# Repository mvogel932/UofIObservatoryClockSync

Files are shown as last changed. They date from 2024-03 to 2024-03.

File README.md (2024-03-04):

# UofIObservatoryClockSync
Self-winding clock synchronizer with accurate timebase
Self-winding clock synchronizer:
Documentation/software:  https://github.com/mvogel932/UofIObservatoryClockSync

General info:

Master clock provides a one-second long pulse once per hour.  It connects the positive power lead to a terminal for that one second.  So what the clock sync circuit needs to do is close a relay for one second once an hour, exactly at 59 min 59 seconds past the hour, ending exactly at the hour.
Per email from Mike Svec on 5/7/23, the self-winding clock uses 3V power.   Bruce Hannon added a transformer on the inside to power the rewind.
Based on my research, it appears the sync coil on the self-winding clock should have a DC resistance of about 6 ohms.  So it will draw about 0.5 amps at 3 volts.

Rev 2 Hardware (as of 2/5/2024):

Controller board:  Adafruit ESP32-S2 Reverse TFT Feather
From <https://www.adafruit.com/product/5345> 

It's basically our ESP32-S2 TFT Feather but with the 240x135 color TFT display on the back-side not the front-side. That makes it great for panel-mounted projects, particularly since we've also got some space for 3 buttons to go along. It's like an all-in-one display interface dev board, powered by the fantastic ESP32-S2 WIFI module.
This feather comes with native USB and 4 MB flash + 2 MB of PSRAM, so it is perfect for use with CircuitPython or Arduino with low-cost WiFi. Native USB means it can act like a keyboard or a disk drive. WiFi means it's awesome for IoT projects. And Feather means it works with the large community of Feather Wings for expandability.
The ESP32-S2 is a highly-integrated, low-power, 2.4 GHz Wi-Fi System-on-Chip (SoC) solution that now has built-in native USB as well as some other interesting new technologies like Time of Flight distance measurements. With its state-of-the-art power and RF performance, this SoC is an ideal choice for a wide variety of application scenarios relating to the Internet of Things (IoT), wearable electronics, and smart homes.
Please note the Feather ESP32-S2 has a single-core 240 MHz chip, so it won't be as fast as ESP32's with dual-core. Also, there is no Bluetooth support. However, we are super excited about the ESP32-S2's native USB which unlocks a lot of capabilities for advanced interfacing! This ESP32-S2 mini-module we are using on the Feather comes with 4 MB flash and 2 MB PSRAM so you can buffer massive JSON files for parsing!
The color TFT is connected to the SPI pins, and uses additional pins for control that are not exposed to the breakout pads. It's the same display as you see here, with 240x135 pixels and is IPS so you get bright color at any angle. The backlight is also connected to a separate pin so you can PWM the backlight up and down as desired.
For low power usage, the Feather has a second RT9080 regulator. The regulator is controlled with a GPIO pin on the enable line and can shut off power to the Stemma QT port and TFT. There is also a separate power pin for the NeoPixel that can be used to disable it for even lower quiescent power. With everything off and in deep sleep mode, the TFT feather uses about 40uA of current.
Features:
	• ESP32-S2 240MHz Tensilica processor - the next generation of ESP32, now with native USB so it can act like a keyboard/mouse, MIDI device, disk drive, etc!
	• Mini module has FCC/CE certification and comes with 4 MByte of Flash and 2 MByte of PSRAM - you can have huge data buffers
	• Color 1.14" IPS TFT with 240x135 pixels - bright and colorful display with ST7789 chipset that can be viewed at any angle.
	• Three User Tactile buttons - D0, D1, and D2. D0/BOOT0 is also used for entering ROM bootloader mode if necessary.
	• Power options - USB type C or Lipoly battery
	• Built-in battery charging when powered over USB-C
	• LiPoly battery monitor - MAX17048 chip actively monitors your battery for voltage and state of charge / percentage reporting over I2C
	• Reset and DFU (BOOT0) buttons to get into the ROM bootloader (which is a USB serial port so you don't need a separate cable!)
	• Serial debug output pin (optional, for checking the hardware serial debug console)
	• STEMMA QT connector for I2C devices, with switchable power, so you can go into low power mode.
	• On/Charge/User LEDs + status NeoPixel with pin-controlled power for low power usage
	• Low Power friendly! In deep sleep mode, we can get down to 40~50uA of current draw from the Lipoly connection. Quiescent current is from the power regulator, ESP32-S2 chip, and Lipoly monitor. Turn off the NeoPixel and external I2C/TFT power for the lowest quiescent current draw.
	• Works with Arduino or CircuitPython

From <https://www.adafruit.com/product/5345> 

Relay board:  Adafruit power relay FeatherWing
https://www.adafruit.com/product/3191
Omron G5LE-14 3 VDC relay
Coil resistance:  22.5 Ohms
Coil current:  133 mA
Must operate voltage: 2.25 VDC
Must release voltage: 0.3 VDC
Operate time:  10 ms
Release time:  5 ms
Inductive load max:  4A at 30 VDC

GPS board: Adafruit Ultimate GPS FeatherWing
https://www.adafruit.com/product/3133

Connector for output to clock synchronizer solenoid:
5.5 x 2.1 mm DC Power Jack Socket Threaded Female Panel Mount Connector Adapter with Dustproof Plug 6Pack
Connector size: 5.5x2.1mm
Mounting hole diameter: 10.8mm

Power input(s) to sync circuit:  USB-C cable to 5.25V 1A plug in power transformer
Output signal to clock:   1 second pulse, 3V, 0.5 amps to power sync solenoid
Source of accurate time:  GPS
Software:  Arduino running on ESP32-S2
Arduino sketch:  Custom software written by Matt Vogel
Arduino GPS library:  Adafruit GPS Library

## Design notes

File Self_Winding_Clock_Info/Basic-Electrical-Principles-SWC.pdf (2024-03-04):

Ken’s Clock Clinic
Clock Restorations and Vintage Dry Cells

1

# Basic Electrical Principles

## for Self Winding Clocks

# Ken Reindel NAWCC Chapter 15

Ken’s Clock Clinic
Clock Restorations and Vintage Dry Cells

2

# Objective

# - To de-mystify electrical principles - Enrich Understanding

## – Technical – How self-winding technology came into being

# - Offer solid technical foundation for working on Self-winding Clocks - This is NOT a course on self winding clock repair (that one is next!)

Ken’s Clock Clinic
Clock Restorations and Vintage Dry Cells

3

# Approach

# - Start with Historical Perspective - Explain simple mathematical relationships - Apply them with a mini lab - Discussion, answer questions

Ken’s Clock Clinic
Clock Restorations and Vintage Dry Cells

4

# Agenda

## - Historical - Basic Electricity - Ohm’s Law - Power Law

– Double the voltage, quadruple the trouble

## - Components

– Resistors
– Batteries
– Coils and Electromagnets
– Contacts

## - Making Basic Electrical Measurements

– Digital Multimeter Basics

## - Mini-Lab

Ken’s Clock Clinic
Clock Restorations and Vintage Dry Cells

5

# The 1700s

Benjamin Franklin, American inventor and politician. In 1752 he established that lightning and Static electricity were fundamentally the same. He also established the conventions of negatively charged electrons and positively charged protons.

Alessandra Volta, Italian mathematician. In 1792 he proved that brine-(saltwater) saturated paper sandwiched in between disks of silver and zinc would produce an electrical potential (electrical pressure). This was the origin of the BATTERY! The unit of electrical potential or pressure was named in his honor.

Ken’s Clock Clinic
Clock Restorations and Vintage Dry Cells

6

# Early 1800s

Andre-Marie Ampere, French Mathematician. In 1826, he published the results of his studies that related electric current flow to magnetism (but gave credit for it to Michael Faraday). The unit of electrical current flow was named after him.

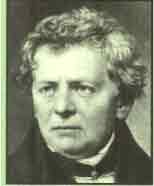
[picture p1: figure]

George Ohm, German Physicist and mathematician. In 1827 he published "The Galvanic Circuit Investigated Mathematically,” quantifying the relationships between electrical potential, electric current flow, and resistance. The unit of resistance was named after him.

Ken’s Clock Clinic
Clock Restorations and Vintage Dry Cells

7

# Significant Advances

Thomas Alva Edison, American Inventor: Between 1850 and well into the early 1900’s, Edison applied the theories of many predecessors to the invention or refinement of the incandescent light, DC motor, DC generator, and first practical storage battery.

Georges Leclanché, French Scientist and Engineer. In 1866 Leclanché developed the first practical 1.5 volt wet cell. Over 20,000 were produced to power telegraphs, clocks, doorbells. Was the forerunner of the Dry Battery (first realized by Carl Gassner and later E. M. Jewett) or modern carbon-zinc cell.

Ken’s Clock Clinic
Clock Restorations and Vintage Dry Cells

8

# The Atom

## - Composed of:

– Protons
– Neutrons
– Electrons

## - Protons and neutrons are tightly bound into a nucleus - Electrons are relatively loosely held and can be moved in and out of atomic shells

Electrons can be moved
from atom to atom by
electrical pressure

Electrons can also be
freed by chemical
reactions, creating
electrical pressure

Ken’s Clock Clinic
Clock Restorations and Vintage Dry Cells

9

# Insulators and Conductors

## Insulators are materials that do not readily allow the electrons in their atoms to move freely from atom to

atom. Examples are glass, wood, air.

## Conductors are materials that freely allow movement of electrons between the individual atoms. Metals are the primary

example.

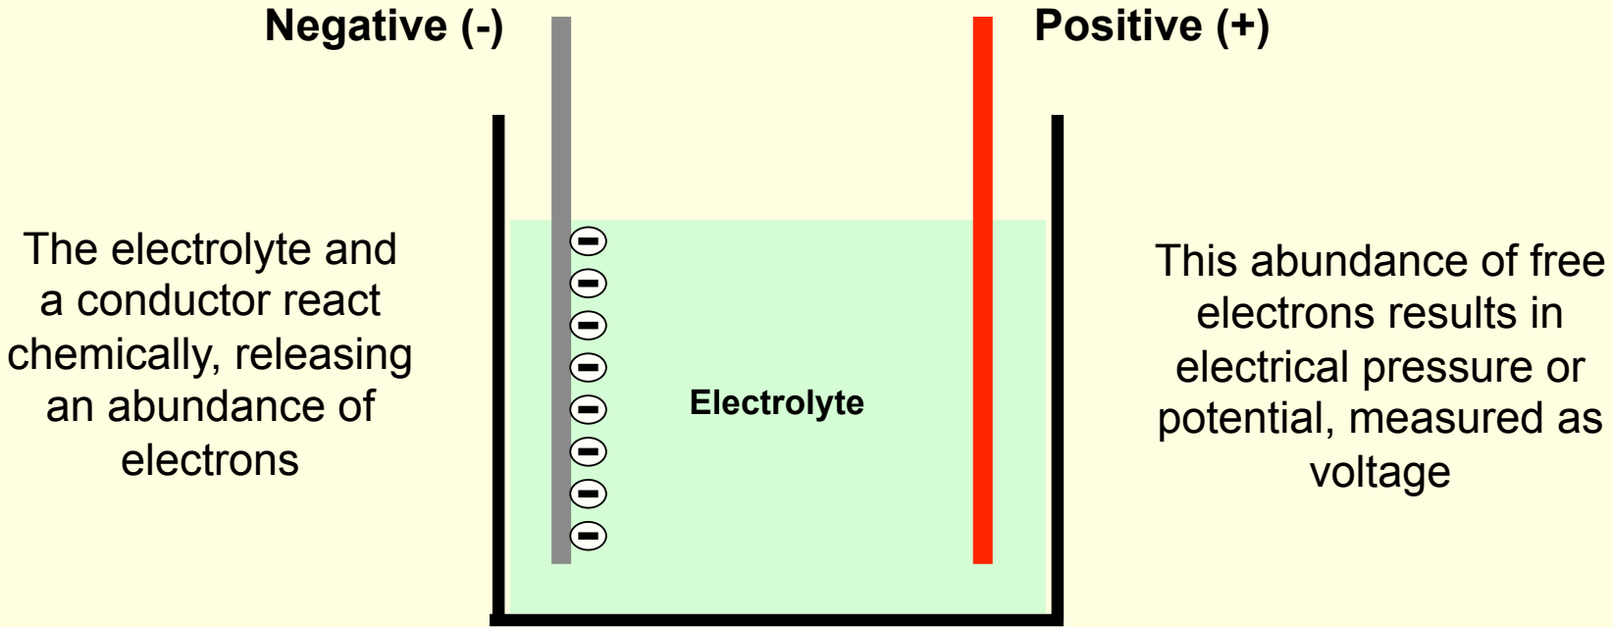
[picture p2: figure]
Negative (-); Positive (+); Electrolyte; The electrolyte and a conductor react chemically, releasing an abundance of electrons; This abundance of free electrons results in electrical pressure or potential, measured as voltage

Ken’s Clock Clinic
Clock Restorations and Vintage Dry Cells

10

# How Batteries Work

## - A device for storing electrical pressure or potential - Consists of 2 conducting plates and an electrolyte

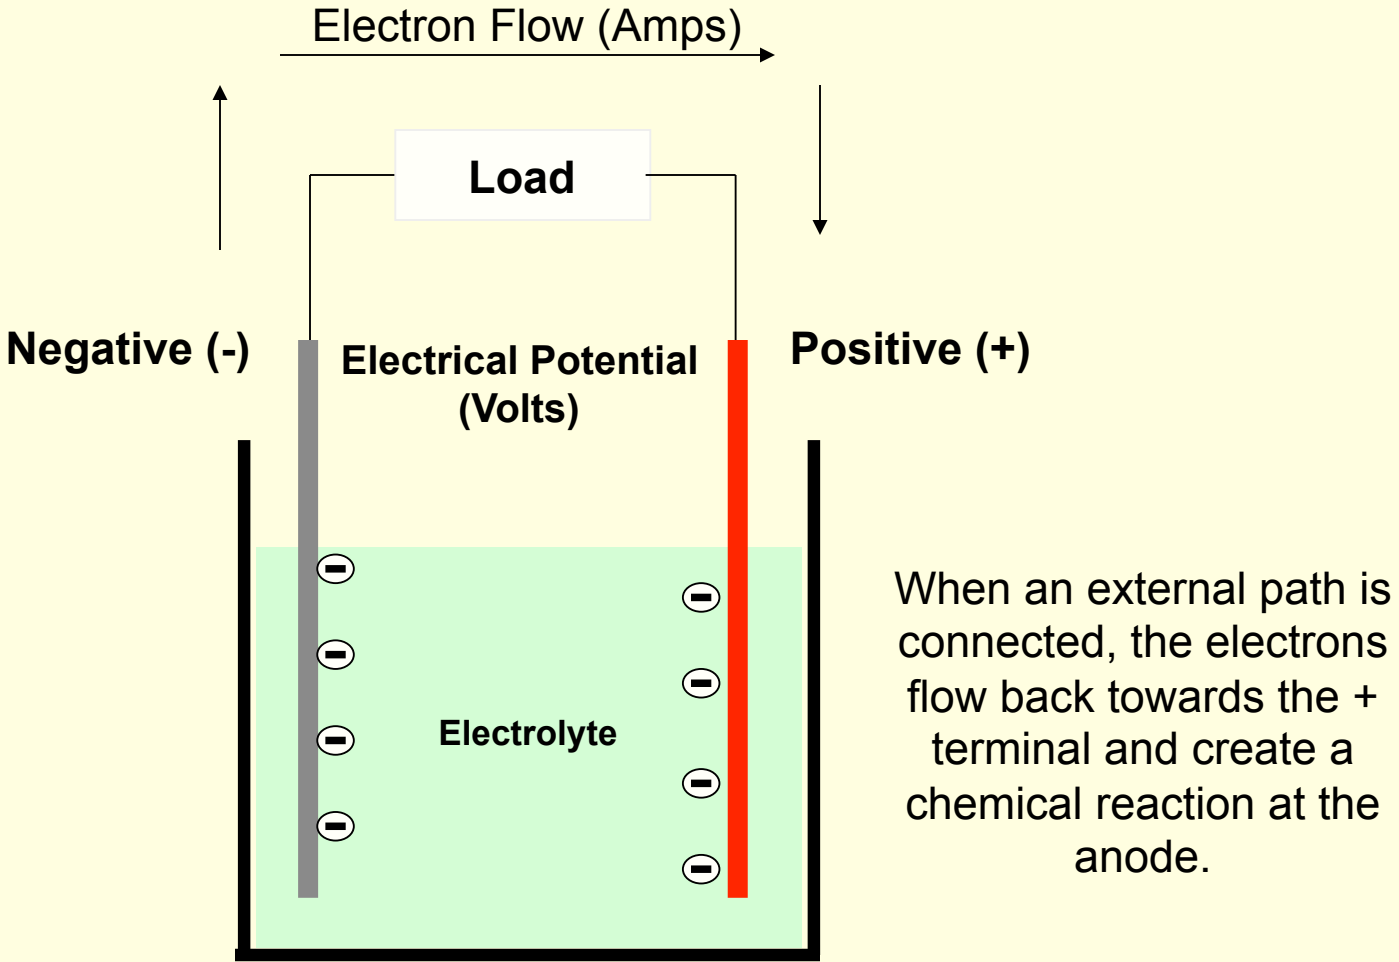
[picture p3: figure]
Load; Electrolyte; Negative (-); Positive (+); Electron Flow (Amps); When an external path is connected, the electrons flow back towards the + terminal and create a chemical reaction at the anode.; Electrical Potential (Volts)

Ken’s Clock Clinic
Clock Restorations and Vintage Dry Cells

11

# Battery Connected

Ken’s Clock Clinic
Clock Restorations and Vintage Dry Cells

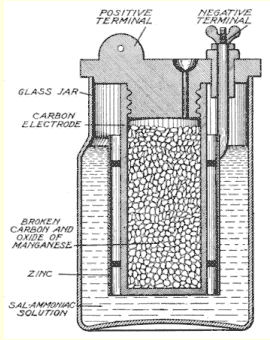
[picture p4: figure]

12

# The Leclanché Cell

# - Earliest practical battery (1866-1900) - Forerunner of Dry Battery - Patented; over 20,000 built - Had a tendency to spill - 1.5 volt cell

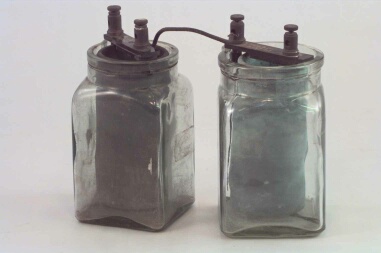
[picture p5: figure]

Ken’s Clock Clinic
Clock Restorations and Vintage Dry Cells

13

# Gonda™ Leclanché Cells

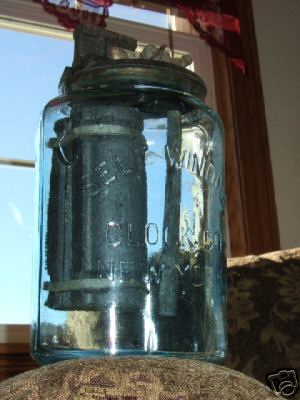
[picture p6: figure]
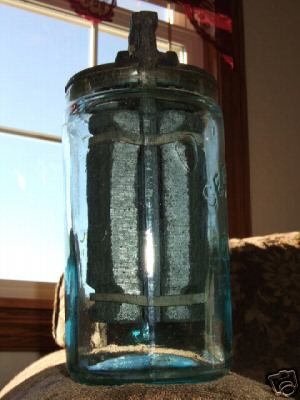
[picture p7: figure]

Ken’s Clock Clinic
Clock Restorations and Vintage Dry Cells

14

# Self Winding Clock Co. Wet Cell

$180 on Ebay

Ken’s Clock Clinic
Clock Restorations and Vintage Dry Cells

15

# The Columbia Battery

## - National Carbon Co. of Lakewood, OH

## – Founded in 1894 – Originally manufactured Leclanché cells – Decades later became Eveready and then Energizer

## - E. M. Jewett and George Little

## – Developed a zinc can-based cell in 1896 – Used carbon as the center cathode (+) – Acidic paste electrolyte with a cardboard separator

– Powered telephone, doorbells, automobiles (ignitor), self-winding clocks, lanterns, etc.

## – Transformed the industry!

# The Columbia Battery

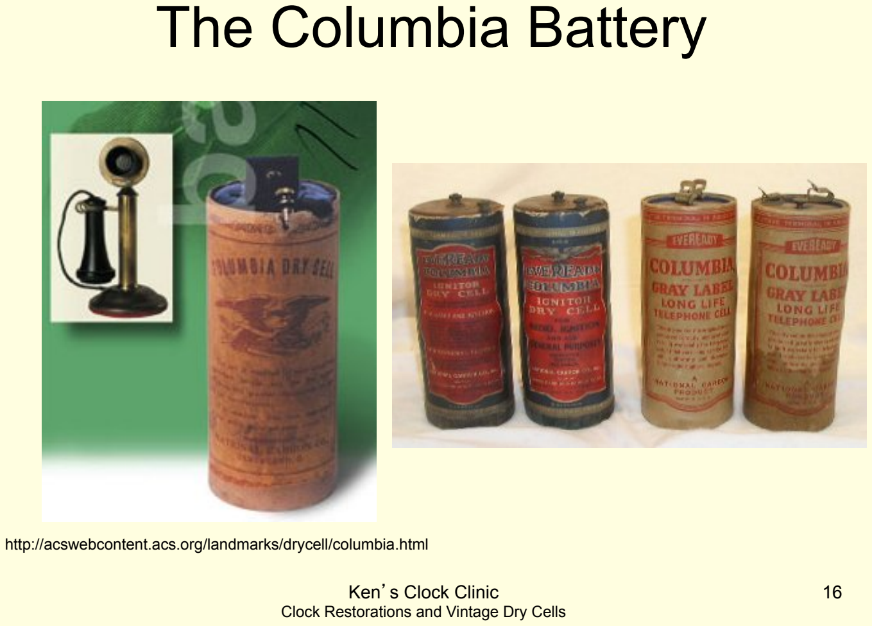
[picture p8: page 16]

Ken’s Clock Clinic
Clock Restorations and Vintage Dry Cells

16

http://acswebcontent.acs.org/landmarks/drycell/columbia.html

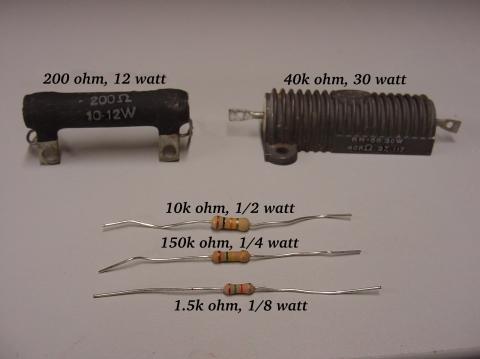
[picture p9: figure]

Ken’s Clock Clinic
Clock Restorations and Vintage Dry Cells

17

# Resistors

# - Many electrical loads are resistive (at least partially)

– Motors, light bulbs, electromagnets, etc.

# - Other examples of resistors:

Resistors are measured in Ohms (Ω)

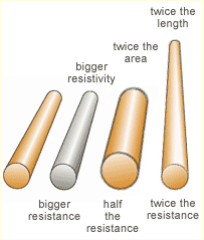
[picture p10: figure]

Ken’s Clock Clinic
Clock Restorations and Vintage Dry Cells

18

# Wire Resistance

# - Wire resistance varies by length and thickness - Also depends on the

type of wire e.g.,

# copper or NiCr

Ken’s Clock Clinic
Clock Restorations and Vintage Dry Cells

19

# SWCC Damping Resistors

Ken’s Clock Clinic
Clock Restorations and Vintage Dry Cells

20

# Elements of Electricity

# - Voltage

## – Electrical Pressure or Potential – Batteries are an example of a voltage source

# - Current

## – A measure of the FLOW of electricity – Measured in Amps

# - Resistance

## – A measure of the restriction to FLOW – Measured in Ohms

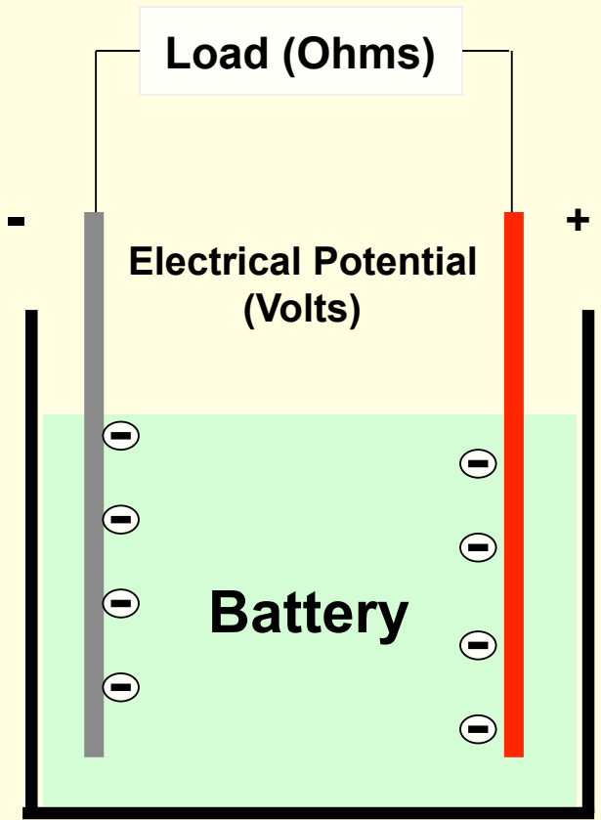
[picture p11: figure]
Load (Ohms); Battery; - + Electrical Potential (Volts)

Ken’s Clock Clinic
Clock Restorations and Vintage Dry Cells

21

# Elements of Electricity

Electron Flow
(Amps)

Power (Watts) = Amps x Volts

Voltage = Amps x Ohms

Also,

Amps = Voltage/Ohms

Ohm’s Law:

Power (Watts) = Volts²/Ohms

## Power is a measure of energy

Ken’s Clock Clinic
Clock Restorations and Vintage Dry Cells

22

# Example Application of Ohm’s Law

## Coil resistance = 6Ω Battery voltage = 3 volts

## How many amps will be needed from battery?

## Answer: Amps = Volts/Ohms = 3 volts/ 6Ω = ½ Amp

6Ω coil

+
3 V

Amps = ?

Ken’s Clock Clinic
Clock Restorations and Vintage Dry Cells

23

Let’s keep going…..

## - For the same circuit:

## How much power is dissipated in the coil?

## Answer:

## Power = Voltage²/Ohms = 3² volts/6Ω = 1.5 watts

6Ω coil

+
3 V

½ Amp

Power = ??

Ken’s Clock Clinic
Clock Restorations and Vintage Dry Cells

24

# One more time…

## - For the same circuit:

## How much more power is dissipated in the coil if we use a Lantern battery which is 6 volts???

## Answer:

# Power = Voltage²/Ohms

## = 6² volts/6Ω = 6 watts or 4x more!!

6Ω coil

+
6 V

Power = ??

1 Amp

Ken’s Clock Clinic

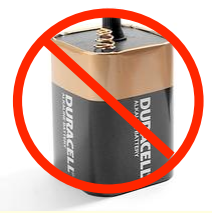
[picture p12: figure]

Clock Restorations and Vintage Dry Cells

25

Lesson Learned…..

# - Double the voltage (6V) forces 4x the energy into the electrical components

# - DO NOT USE in 3V clocks

## – Unless you use a voltage converter

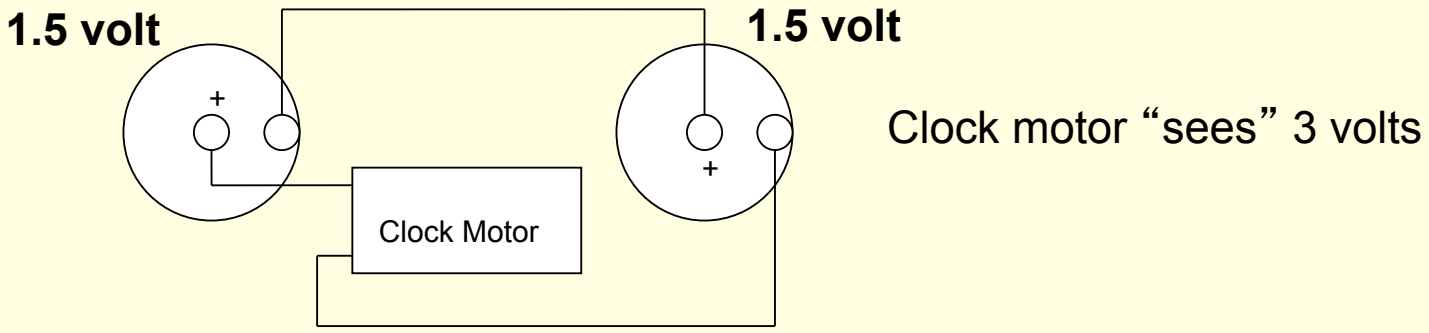
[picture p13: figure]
Clock Motor; 1.5 volt; Clock motor “; sees; ” 3 volts

Ken’s Clock Clinic
Clock Restorations and Vintage Dry Cells

26

# Series Circuits

# - Batteries in SERIES add:

# - Resistors in SERIES also add:

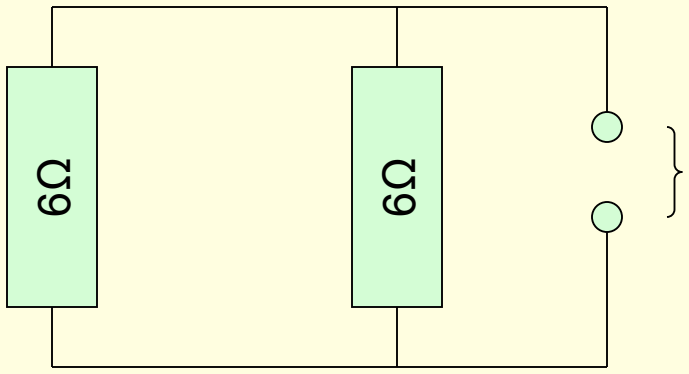
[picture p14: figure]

Ken’s Clock Clinic
Clock Restorations and Vintage Dry Cells

27

# Parallel Circuits

## - Batteries in PARALLEL of same voltage will output that voltage, but increase Amperage capacity

N like value resistors in
parallel reduce by:

Rp = R/N

6Ω// 6Ω = 3Ω

Ken’s Clock Clinic
Clock Restorations and Vintage Dry Cells

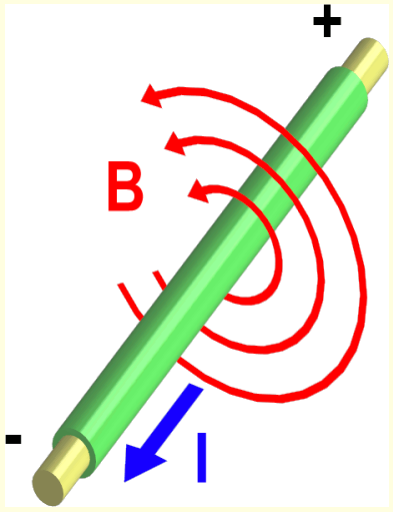
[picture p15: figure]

28

# Coils and Electromagnets

# - If a current is passed through a wire, a magnetic field results - This magnetic field encircles the wire as

shown.

# - The magnetic field will form around magnetic materials if we let it

Ken’s Clock Clinic

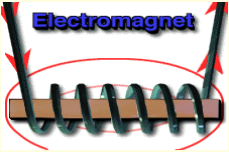
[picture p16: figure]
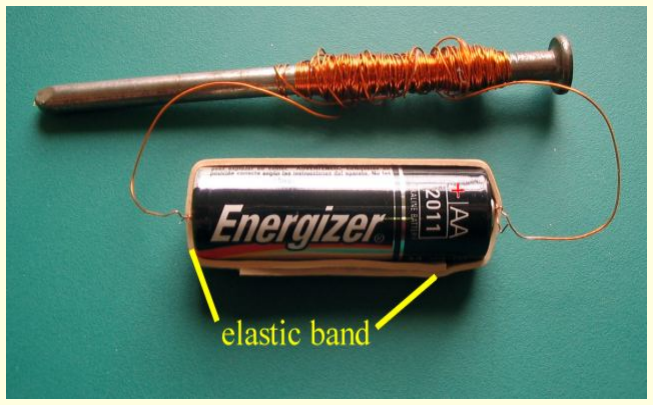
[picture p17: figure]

Clock Restorations and Vintage Dry Cells

29

# Coils and Electromagnets

## •Winding multiple turns around a core will concentrate the magnetic field as

shown.

## •An example of a simple electromagnet can be made using enameled wire wrapped around a nail!

## •All coils have some winding resistance resulting from the copper

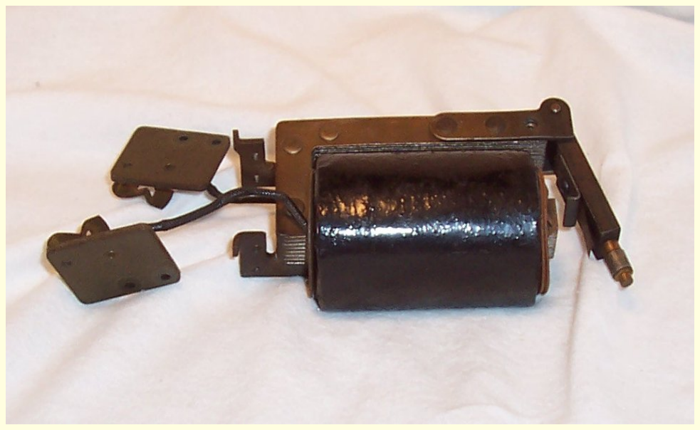
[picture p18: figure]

Ken’s Clock Clinic
Clock Restorations and Vintage Dry Cells

30

# Challenges with Coils

## - What happens when I energize this synchronizer coil?

## - Current will flow through the coil

## - Amps = V/(coil R)

## - Example: If V =3 volts and R is 6 Ω, then:

## Amps = 3V/6Ω = 0.5 Amp

Ken’s Clock Clinic

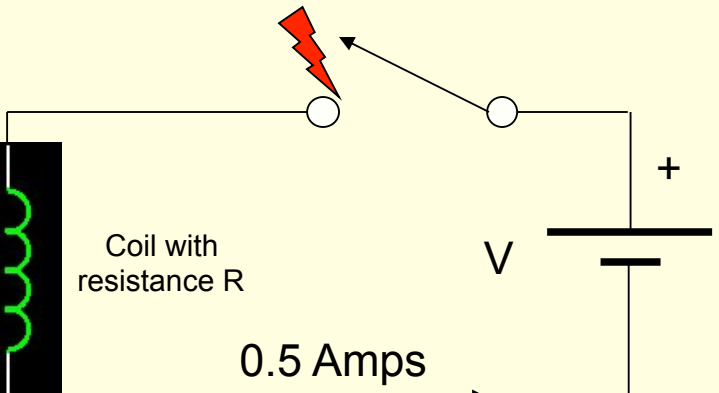
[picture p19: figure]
Coil with; resistance R; 0.5 Amps

Clock Restorations and Vintage Dry Cells

31

# Challenges with Coils

# - What happens when we disconnect the coil?

### 1. Energy is stored in the coil as an

electromagnetic field. That’s the nature of a coil.

### 2. So, when the switch is opened, the

current will want to keep flowing in the coil.

### 3. It will increase its voltage until the

contact arcs over (100’s or 1000’

s
of volts).

### 4. The “spot” temperature from this

arc is hot enough to melt metal, thus pitting and damaging the contacts.
-1000V
3V | 0V

Waveform at Contact

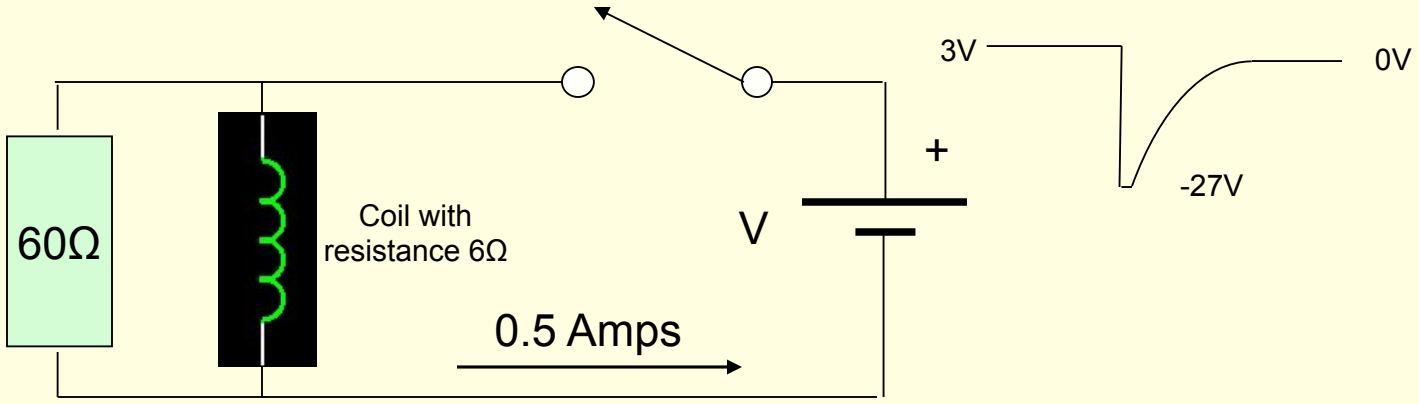
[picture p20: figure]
Coil with; resistance 6Ω; 0.5 Amps

Ken’s Clock Clinic
Clock Restorations and Vintage Dry Cells

32

# Challenges with Coils

# - Question: How do I prevent this? - Answer: Create somewhere else for the

coil current to go when the contact opens.

Flyback current

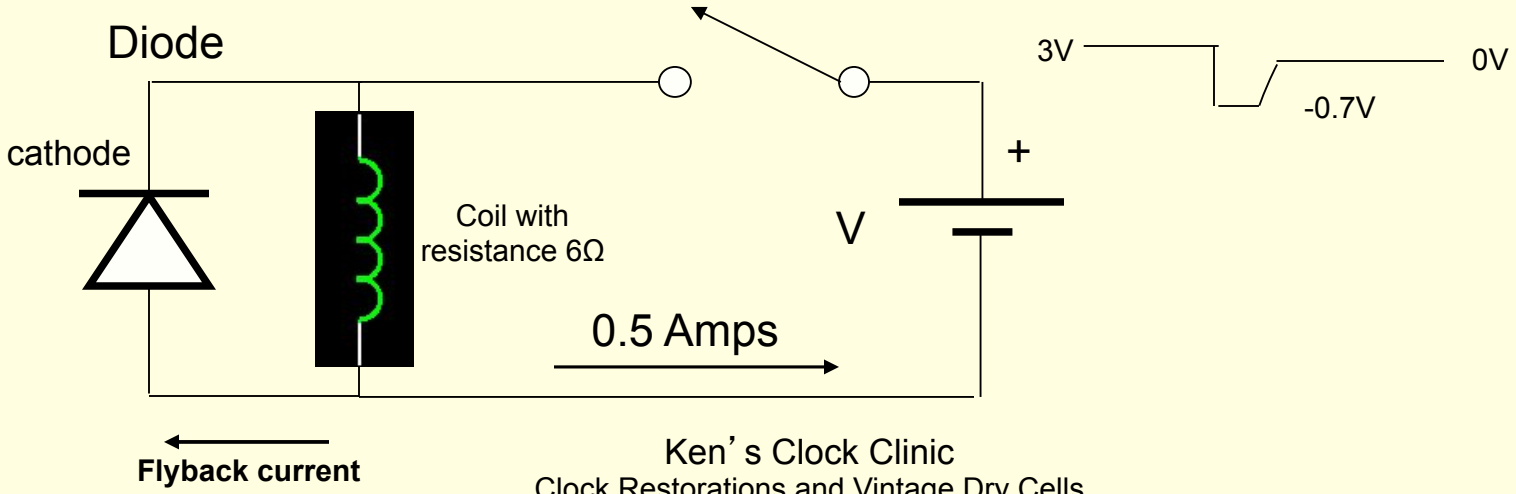
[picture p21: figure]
Ken’s Clock Clinic; Coil with; resistance 6Ω; 0.5 Amps; Flyback current; cathode; Diode

Clock Restorations and Vintage Dry Cells

33

# Challenges with Coils

- Most common option is a Damping resistor,

## usually selected to be 10x the value of the coil

resistance.

## - Another option is a diode, but this was obviously

not used in vintage days.

Ken’s Clock Clinic
Clock Restorations and Vintage Dry Cells

34

# Contacts

# - What makes a good contact???

– Largely depends on the application, but….

# - Low contact resistance - Resistant to oxidation

## – And, therefore, burning – Probably also means high melting temp

# - Good hardness—wears well over time

Ken’s Clock Clinic
Clock Restorations and Vintage Dry Cells

35

# Contacts

## - What kind of materials offer these qualities?

Material | Low Contact R | Resistance to Surface Films | Hardness (wears well)
Gold | Better | Best | Poor
Platinum | Better | Best | Better (especially Platinum-Iridium)
Silver | Best (initially) | Fair | Good
Tungsten | Good | Good | Best
Copper | Best (initially) | Poor | Poor

Ken’s Clock Clinic
Clock Restorations and Vintage Dry Cells

36

# Contacts

# - Platinum is the best pure material (non alloy) - Platinum-iridium is great because of additional hardness - Unfortunately both are VERY EXPENSIVE - But they are WORTH IT!

## – Clocks restored with platinum will run much longer

Ken’s Clock Clinic
Clock Restorations and Vintage Dry Cells

37

# DeoxIT® and DeoxIT® Gold G100L

## - Caig Laboratories - Proven over 50 year history - Unbelievable results – Examples

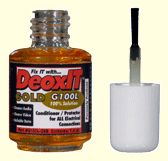
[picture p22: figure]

## - Only a very small quantity needed on CLEAN contacts to preserve them indefinitely

## – Don’t flood contact with it

## - Possible lubricant for Style A motor bearings and commutators

# - http://store.caig.com

ACCT113 2292 1560 AR5GrWbv 1627 http://store

Ken’s Clock Clinic

Clock Restorations and Vintage Dry Cells

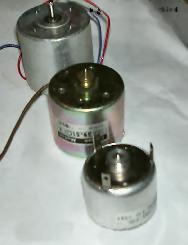
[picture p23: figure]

38

# Electric Motors

## - Electromagnetism is exploited

– Opposite magnetic poles attract; like poles repel

## - Rotation causes reversal of the electromagnetic field because of the commutator

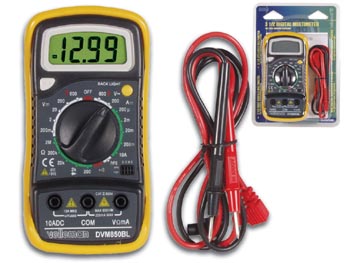
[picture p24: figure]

Ken’s Clock Clinic
Clock Restorations and Vintage Dry Cells

39

# Basic Electrical Measurements

## - The standard instrument for basic electrical measurements is the DMM (Digital MultiMeter) - Multi Function

– Volts
– Ohms
– Amps
– Continuity
– Diode Test

## - Accuracy ~1%

– Good enough for most if
not all clock work

Ken’s Clock Clinic
Clock Restorations and Vintage Dry Cells

40

# Important Aspects of DMM Measurements

## - Know your DMM

## – Make sure the range is appropriate for what you expect to measure!! – Make sure the leads are in the right place – Make practice measurements before doing anything real

## - Make sure you have a good zero

## – If you don’t, subtract the offset from your measurement to obtain most accurate reading – Especially true with low voltages

Ken’s Clock Clinic
Clock Restorations and Vintage Dry Cells

41

# Experiment 1: Measure the resistance of devices

# - Set DMM to 200 ohm range

# 1. Touch both probe tips to a terminal 2. Record “offset” 3. Measure device of interest eg Terminal 3 and Terminal 4 4. Subtract value in Step 2 from value in

Step 3.

Ken’s Clock Clinic
Clock Restorations and Vintage Dry Cells

42

# Experiment 2: Measuring Voltage

# - Set DMM to 20 Volts DC range

1. Measure battery terminal voltage.

# 2. Now, connect battery to light bulb

(Terminals 5 and 6).
3. Measure battery terminal voltage again.
4. Compare result from 2 to result from 4.

Ken’s Clock Clinic
Clock Restorations and Vintage Dry Cells

43

# Experiment 3: Stall Current of Motor

# - Connect a wire between Terminal 2 and Terminal 6 - Connect battery (with test clips) between Terminal 1 and Terminal 5 - Stop motor with fingers - What happens??? Why???

Ken’s Clock Clinic
Clock Restorations and Vintage Dry Cells

44

# Experiment 4: Coil Arcing

## 1. Connect one of the battery leads to Terminal 3

using test clip.

## 2. Touch other test clip to Terminal 4 3. As you do, notice the spark. Why is there a spark there? 4. Now, connect Terminal 3 to Terminal 7

5. Likewise connect Terminal 4 to Terminal 8.
6. Repeat the test in 1-2 above.

## - What happened? Why?

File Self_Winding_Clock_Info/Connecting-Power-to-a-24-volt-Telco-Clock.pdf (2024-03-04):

### Connecting Power to a 24 volt Telco Clock

Below is a picture of a typical Self Winding Clock Co. 24 volt Telco parlor clock, taken with the dial removed. This particular clock does not have a synchronizer coil. Note that the upper movement terminal on the left, marked A, connects to the Fahenstock terminal C which connects to the manual winding switch. This is very important in order for the winding switch to work properly and MUST NOT be connected anywhere else. Movement terminal B connects to Fahenstock terminal D. Be sure that the black curled grounding wire, which connects to the winding switch, is in place. This is a good time to make sure that the contact areas of the winding switch are clean. If not, remove the switch and clean it with Scotch-Brite. Do not use Scotch-Brite near the movement since it will generate abrasive dust and you don’t want that getting into the movement.

The 24 volt DC battery or power source is then connected to terminals E and F. Polarity is not important. Again, be sure that these and all other terminals are clean and oxidefree. If they remain oxidized and dirty, you may experience intermittent connections. The remaining terminals and switches in the clock are not used. They were originally meant to provide the 6 second timing signals to the billing system or printer. Don’t connect batteries to these terminals or switches.


The next picture shows the wiring installed as described above, but in addition, also shows the Model 1900R-24V connected to the clock. Note that the black and red battery wires are connected to terminals E and F as described above.

The following are some close ups showing the battery and the terminal connections above:

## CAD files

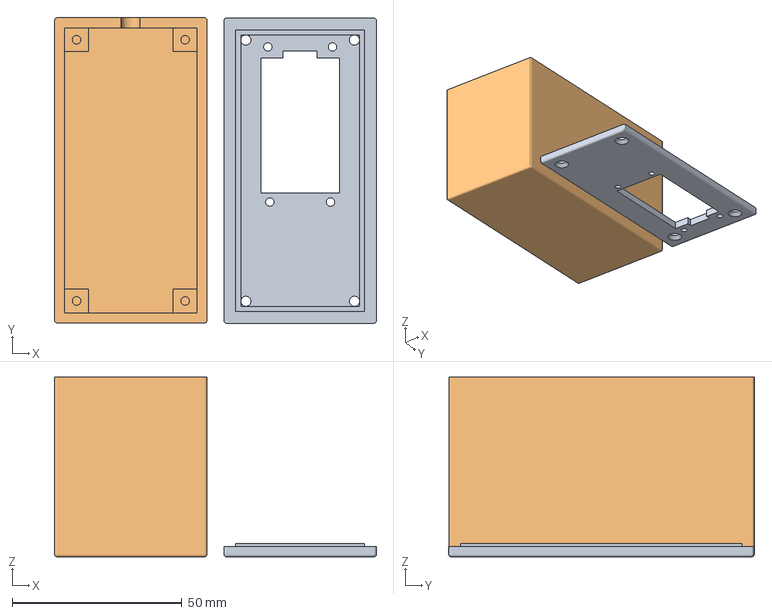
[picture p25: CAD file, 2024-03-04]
Case/Case v7.3mf
94.9 x 90.1 x 53.0 mm
CaseCover v10.stl
Case v7.stl

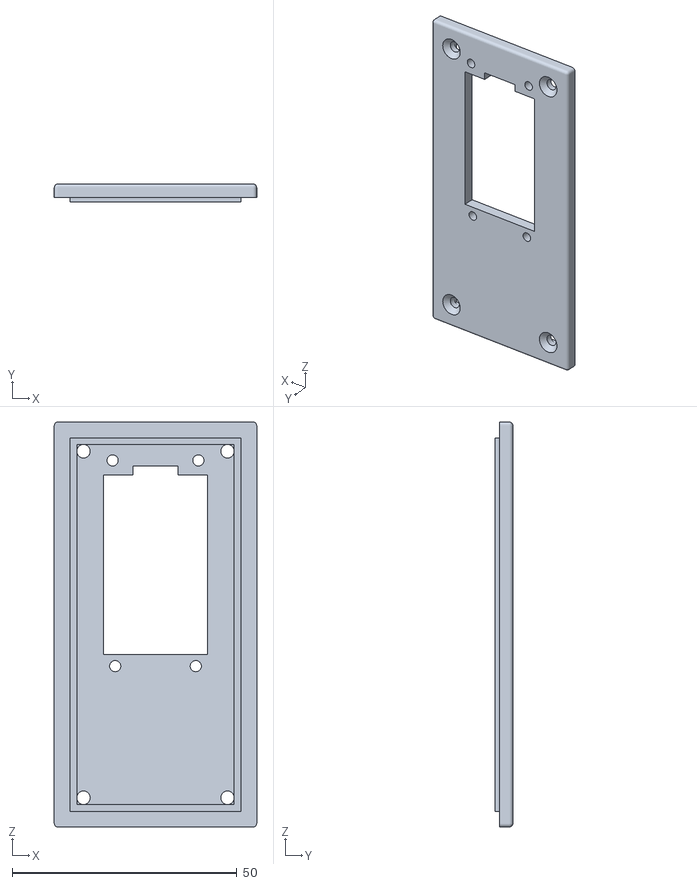
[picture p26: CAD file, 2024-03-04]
Case/CaseCover v10.stl
45.0 x 4.00 x 90.0

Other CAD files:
Case/Case v7.stl

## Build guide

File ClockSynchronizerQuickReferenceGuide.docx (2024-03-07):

University of Illinois Observatory self-winding clock synchronizer

Quick Reference Guide

Version: 1.0 Date: 3/7/2024 Author: Matthew Vogel

Summary:

The self-winding clock synchronizer is intended to be used with the self-winding clock in the Observatory. The synchronizer outputs a one second long pulse to the synchronizing coil of the self-winding clock once an hour, starting at 59 minutes, 59 seconds past the hour. This synchronizes the clock and ensures that the clock maintains the correct time. The synchronizer gets its time base from the GPS satellites.

Connecting the synchronizer:

The synchronizer has a connector for sending the sync pulse signal to the clock. The connector is a two conductor 5.5 x 2.1mm jack mounted on the side of the synchronizer. Wire a two-conductor cable to a matching 5.5 x 2.1mm plug, then connect the other end of the two wires to the two terminals of the synchronizer coil inside the clock. The synchronizer output pulse is powered by the internal lithium-ion battery of the synchronizer, so the output voltage will be between 3.7V and 4.2V, depending on the state of charge of the battery.

Powering the synchronizer:

The synchronizer has an internal battery that will run the synchronizer for about 10 hours. To keep this battery charged, plug the USB cable from the synchronizer into a suitable USB power supply (anything that can output 5V and at least 0.5A). To power off the synchronizer, unplug the USB cable from the power supply and turn off the power switch on the side of the synchronizer. During normal use, ensure that the power switch is “on” in order to keep the battery charged.

Using the synchronizer:

Once the synchronizer is powered and connected to the clock, it should automatically start sending the sync pulse to the clock once an hour, as long as the synchronizer can get a signal from the GPS satellites to maintain its internal time base.

There are three buttons to the left of the display on the synchronizer:

Button 1 (top): This button can be used to enable/disable the synchronizer output pulse. Each press of the button toggles the enable/disable state of the sync output. Note that the sync output cannot be enabled if the synchronizer is unable to get a GPS signal to maintain its internal time base.

Button 2 (middle): This button can be used to manually trigger the synchronizer output pulse (e.g., for testing the clock’s synchronizer coil). The sync output will be active for as long as this button is pressed.

Button 3 (bottom): This button is not used.

Location of documentation:

https://github.com/mvogel932/UofIObservatoryClockSync

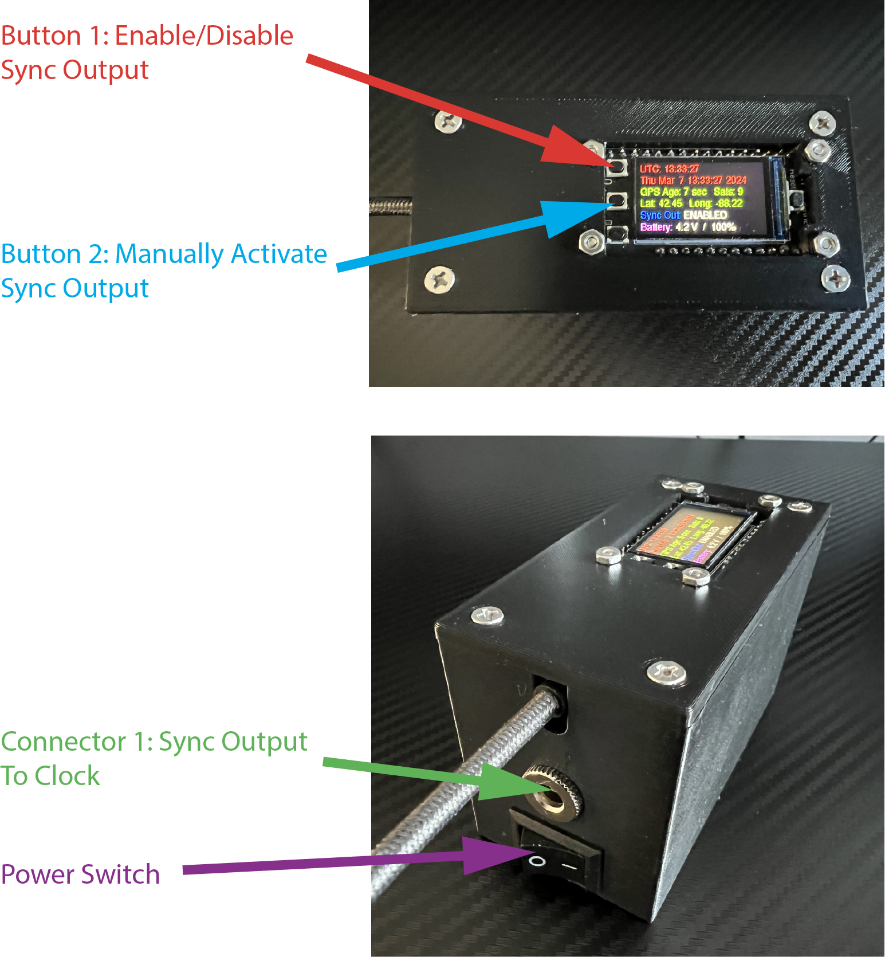
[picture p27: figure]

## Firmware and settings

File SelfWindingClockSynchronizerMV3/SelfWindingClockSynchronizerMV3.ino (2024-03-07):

/*
* Self-winding clock synchronizer software
*
* The purpose of this software is to maintain an accurate timebase and send a synchronizing pulse once an hour to a
* self-winding clock.
*
* The accurate timebase is obtained from GPS satellites.
*
* Hardware is based on the following:
*
* - Adafruit ESP32-S2 Reverse TFT Feather ( https://www.adafruit.com/product/5345 )
*   - Contains:
*     - ESP32-S2 Tensilica SOC, 240 MHz single-core, native USB, WiFi
*     - 1.14" 240x135 pixel color TFT display with ST7789 chipset
*     - 4 MB flash memory
*     - 2 MB PSRAM memory
*     - MAX17048 lithium-ion battery charge/fuel gauge IC
*     - STEMMA QT connector (JST SH 4-pin) for I2C devices
*     - NeoPixel RGB LED status indicator
*     - Three user interface buttons
*     - USB-C connector for charging lithium-ion battery and for serial communications with a PC
*
* - Adafruit Ultimate GPS FeatherWing ( https://www.adafruit.com/product/3133 )
*
* - Adafruit Power Relay FeatherWing ( https://www.adafruit.com/product/3191 )
*
*
* Arduino libraries:
* - Adafruit_MAX1704X - Library for MAX17048 lithium-ion fuel gauge IC
* - Adafruit_NeoPixel - Library for Adafruit NeoPixel single-wire based RGB LED pixel
* - Adafruit_ST7789   - Library for Adafruit 1.14" color TFT display with SPI and ST7789 TFT driver
* - Adafruit_GPS      - Library for Adafruit GPS module
* - ESP32Time         - Library for setting and retrieving internal RTC time on ESP32 boards, by fbiego
*
* Inputs:
*   D0 : ENABLE_DISABLE_OUTPUT - Enable/disable sync relay output (pin pulled HIGH by default, goes LOW when pressed)
*   D1 : TRIGGER_OUTPUT        - Manually trigger sync relay output (for as long as the button is held down) (pin pulled LOW by default, goes HIGH when pressed)
*
* Outputs:
*   Pin 10: Output signal to coil of relay for energizing the synchronizer of the self-winding clock (also red LED on relay board)
*   Pin 13: Output to red LED on ESP32 board (next to USB-C connector) (HIGH is on)
*
*/


// #defines
// Need to include this #define to have GPS library use hardware serial instead of software serial
#define NO_SW_SERIAL
#define GPSSerial Serial1
#define ONE_DAY_IN_SECONDS (60 * 60 * 24)
#define ONE_DAY_IN_MILLISECONDS (1000 * 60 * 60 * 24)
#define NUM_GPS_MSGS_RCVD_FOR_TIME_TO_BE_VALID    3
// Constants for GPIO outputs
#define ENABLE_DISABLE_OUTPUT             0
#define TRIGGER_OUTPUT                    1
#define CLOCK_SYNC                        10    /* Output pin for clock synchronizer relay control */
#define RED_LED                           13
#define ENABLE_DISABLE_OUTPUT_ACTIVE      LOW
#define TRIGGER_OUTPUT_ACTIVE             HIGH
#define RED_LED_ACTIVE                    HIGH
#define RED_LED_INACTIVE                  LOW

// #includes
#include <Arduino.h>
#include <Adafruit_GPS.h>
#include "Adafruit_MAX1704X.h"
#include <Adafruit_NeoPixel.h>
#include <Adafruit_ST7789.h>
#include "Adafruit_TestBed.h"
#include <ESP32Time.h>
#include <Fonts/FreeSans12pt7b.h>
#include <Fonts/FreeSans9pt7b.h>


// Global variables
uint8_t gMainLoopCounter = 0;                         // Main loop counter
bool gSynchronizerOutputManuallyDisabled = false;     // True if the synchronizer output is manually disabled
bool gRTCTimeValid = false;                           // True if the RTC time is valid
bool gGPSTimeValid = false;                           // True if the GPS time is valid
bool gRTCNeverSyncedToGPS = true;                     // Set to false the first time the RTC gets synced to GPS time base
nmea_float_t gSecondsSinceLastValidGPSTime;           // Seconds since the last valid GPS time was received (equal to 0 if never received)
unsigned long gTimeRTCLastSyncedToGPS = 0;            // Time (in milliseconds since board booted up) when RTC was last synced to GPS time base
uint32_t gNumGPSMsgsRcvd = 0;                         // Number of times a message has been received from the GPS module
bool gMAX17048_OK = true;                             // True if MAX17048 battery charger/fuel gauge IC is okay
bool gTriggerOutputActivePreviously = false;          // True if trigger output button was active previous time thru the loop
int  gPreviousPinValEnableDisableOutput;              // Previous pin value of enable/disable output button
int  gPreviousPinValTriggerOutput;                    // Previous pin value of trigger output button
extern Adafruit_TestBed TB;
Adafruit_MAX17048 gLiPo;                              // Adafruit lithium-ion battery charger/fuel gauge object
Adafruit_ST7789 gDisplay = Adafruit_ST7789(TFT_CS, TFT_DC, TFT_RST);  // Adafruit TFT LCD display object
GFXcanvas16 gCanvas(240, 135);                        // A GFX 16-bit canvas context for graphics, part of the Adafruit GFX graphics class
Adafruit_GPS GPS(&GPSSerial);                         // Adafruit GPS object for communicating with GPS module
ESP32Time rtc;                                        // ESP32 RTC object


//Function prototypes
void readGPS();                                       // Get data from GPS module
void syncRTCtoGPS();                                  // Sync the RTC to the GPS time base to keep the RTC accurate
void updateDisplay();                                 // Update the LCD display
void updateRTCTimeWithGPSTime();                      // Update the internal RTC time with the latest GPS time


// Setup
void setup() {
  // Set clock synchronizer GPIO pin to be an output and turn it off
  pinMode(CLOCK_SYNC, OUTPUT);
  digitalWrite(CLOCK_SYNC, LOW);

  Serial.begin(115200);
  //while (! Serial) delay(10);

  // Delay to allow serial to become ready
  delay(500);

  // Initialize the RTC
  rtc.setTime(0, 0, 14, 26, 2, 2024);                     // Default date/time to 2/26/2024 2:00 PM

  // Start the GPS software at 9600 baud rate
  GPS.begin(9600);
  GPS.sendCommand(PMTK_SET_NMEA_OUTPUT_RMCGGA);           // Turn on RMC (recommended minimum) and GGA (fix data)
  GPS.sendCommand(PMTK_SET_NMEA_UPDATE_100_MILLIHERTZ);   // 10 second update time
  GPS.sendCommand(PGCMD_ANTENNA);                         // Request updates on antenna status
  delay(1000);
  GPSSerial.println(PMTK_Q_RELEASE);                      // Ask for GPS firmware version

  // Start the NeoPixel RGB LED
  TB.neopixelPin = PIN_NEOPIXEL;
  TB.neopixelNum = 1; 
  TB.begin();
  TB.setColor(WHITE);

  // Start the LCD display
  gDisplay.init(135, 240);            // Init ST7789 240x135
  gDisplay.setRotation(3);
//  gCanvas.setFont(&FreeSans12pt7b);
  gCanvas.setFont(&FreeSans9pt7b);
  gCanvas.setTextColor(ST77XX_WHITE); 
  delay(500);

  // Activate the LCD backlight
  pinMode(TFT_BACKLITE, OUTPUT);
  digitalWrite(TFT_BACKLITE, HIGH);

  // Start the lithium ion battery charger/monitor
  if (!gLiPo.begin()) {
    Serial.println(F("Could not find Adafruit MAX17048?\nMake sure a battery is plugged in!"));
    gMAX17048_OK = false;
  }
  if (gMAX17048_OK) {
    Serial.print(F("Found MAX17048"));
    Serial.print(F(" with Chip ID: 0x")); 
    Serial.println(gLiPo.getChipID(), HEX);
  }

  // Set user buttons to be inputs
  pinMode(ENABLE_DISABLE_OUTPUT, INPUT_PULLUP);
  pinMode(TRIGGER_OUTPUT, INPUT_PULLDOWN);
  pinMode(2, INPUT_PULLDOWN);

  // Set red LED to be output
  pinMode(RED_LED, OUTPUT);
  digitalWrite(RED_LED, RED_LED_INACTIVE);

  // Set the previous state of the buttons to the current value so we don't detect a button press/release at startup
  gPreviousPinValEnableDisableOutput = digitalRead(ENABLE_DISABLE_OUTPUT);
  gPreviousPinValTriggerOutput       = digitalRead(TRIGGER_OUTPUT);

  Serial.println();
  Serial.println();
  Serial.println();
  Serial.println();
  Serial.println();
  Serial.println("************************************************");
  Serial.println("************************************************");
  Serial.println("********** Clock synchronizer startup **********");
  Serial.println("************************************************");
  Serial.println("************************************************");
}


// Main loop
void loop() {

  // Get data from the GPS module
  readGPS();

  // Update GPS time valid/not valid state
  // GPS time valid logic:
  // 1) When program first starts running, GPS time is invalid
  // 2) GPS time becomes valid when "time since last valid GPS time" becomes less than or equal to 120 seconds AND at least NUM_GPS_MSGS_RCVD_FOR_TIME_TO_BE_VALID GPS messages have been received
  // 3) GPS time becomes invalid when "time since last valid GPS time" becomes greater than 120 seconds

  // See how long it has been since we last received a valid GPS time
  gSecondsSinceLastValidGPSTime = GPS.secondsSinceTime();

  if ((gGPSTimeValid) && (gSecondsSinceLastValidGPSTime > 120)) {
    // Time is now invalid
    gGPSTimeValid = false;
    Serial.println("ERR: GPS TIME NOT VALID");
    Serial.print("Sec since valid: ");
    Serial.println(gSecondsSinceLastValidGPSTime);
  }

  if ( (!gGPSTimeValid) && (gSecondsSinceLastValidGPSTime <= 120) && (gNumGPSMsgsRcvd >= NUM_GPS_MSGS_RCVD_FOR_TIME_TO_BE_VALID) ) {
    // Time is now valid
    gGPSTimeValid = true;
    Serial.println("INFO: GPS TIME VALID");
    Serial.print("Sec since valid: ");
    Serial.println(gSecondsSinceLastValidGPSTime);
  }

  // Update RTC time valid/not valid state
  // RTC time valid logic:
  // 1) When program first starts running, RTC time is invalid
  // 2) RTC time becomes valid when RTC time gets synced to GPS time (handled lower down in the main loop)
  // 3) RTC time becomes invalid when "time since RTC time last synced to GPS time" becomes greater than 3 days

  if ( (gRTCTimeValid) && ( (millis() - gTimeRTCLastSyncedToGPS) > (3 * ONE_DAY_IN_MILLISECONDS) ) ) {
    // Time is now invalid
    gRTCTimeValid = false;
    Serial.println("ERR: RTC TIME NOT VALID");
    Serial.print("Sec since RTC synced to GPS: ");
    Serial.println(gTimeRTCLastSyncedToGPS / 1000);
  }


  // Check if we need to sync the RTC time to the GPS time base
  // RTC time gets synced to GPS time IF:
  //  GPS time is valid
  //      *AND*
  //  ( RTC has never been synced to GPS  *AND*  at least NUM_GPS_MSGS_RCVD_FOR_TIME_TO_BE_VALID GPS messages have been received
  //      *OR*
  //    More than one day has elapsed since RTC was last synced to GPS )
  //
  if ( gGPSTimeValid && ( ( (gRTCNeverSyncedToGPS) && (gNumGPSMsgsRcvd >= NUM_GPS_MSGS_RCVD_FOR_TIME_TO_BE_VALID) ) || ( (millis() - gTimeRTCLastSyncedToGPS > ONE_DAY_IN_MILLISECONDS) ) ) ) {
    gRTCNeverSyncedToGPS = false;
    gTimeRTCLastSyncedToGPS = millis();
    syncRTCtoGPS();
    // If RTC had been previously invalid, then do some stuff now that RTC is valid
    if (!gRTCTimeValid) {
      // Time is now valid
      gRTCTimeValid = true;
      Serial.println("INFO: RTC TIME VALID");
    }
  }


  // Check for user inputs
  // Check for enable/disable output button
  int pinVal = digitalRead(ENABLE_DISABLE_OUTPUT);
  if ( (pinVal == ENABLE_DISABLE_OUTPUT_ACTIVE) && (pinVal != gPreviousPinValEnableDisableOutput) ){
    // Enable/disable output button is newly pressed, so toggle enable/disable state of output
    gSynchronizerOutputManuallyDisabled = !gSynchronizerOutputManuallyDisabled;         // Toggle the enable/disable flag
  }
  gPreviousPinValEnableDisableOutput = pinVal;        // Remember the current reading for next time thru the loop

  // Check for manual output trigger button
  pinVal = digitalRead(TRIGGER_OUTPUT);
  if (pinVal == TRIGGER_OUTPUT_ACTIVE) {
    if (pinVal != gPreviousPinValTriggerOutput) {
      // Turn on the sync relay output
      digitalWrite(CLOCK_SYNC, HIGH);
      digitalWrite(RED_LED, RED_LED_ACTIVE);
      Serial.println("PULSE ON MANUAL");
    }
  } else if (pinVal != gPreviousPinValTriggerOutput){
    digitalWrite(CLOCK_SYNC, LOW);
    digitalWrite(RED_LED, RED_LED_INACTIVE);
    Serial.println("PULSE OFF MANUAL");
  }
  gPreviousPinValTriggerOutput = pinVal;              // Remember the current reading for next time thru the loop


  // Activate/deactivate clock synchronizer relay
  // If the RTC time is valid, then see if need to activate or deactivate the clock synchronizer relay
  uint8_t seconds = rtc.getSecond();
  uint8_t minutes = rtc.getMinute();
  if ( (gRTCTimeValid) && (!gSynchronizerOutputManuallyDisabled) ) {
    // Once an hour, one second before the top of the hour, activate the self-winding clock synchronizer circuit to make sure clock is set properly
    if ( (minutes == 59) && (seconds == 59) )
    {
      if (digitalRead(CLOCK_SYNC) == LOW)
      {
        digitalWrite(CLOCK_SYNC, HIGH);   // Activate the clock synchronizer circuit (will get de-activated one second later)
        digitalWrite(RED_LED, RED_LED_ACTIVE);
        Serial.print("PULSE ON    ");
        Serial.print("Min: ");
        Serial.print(minutes);
        Serial.print("  Sec: ");
        Serial.println(seconds);
      }
    }
  }

  // Need to deactivate the clock sync output one second after it is activated.  It gets activated one second before
  // the top of the hour, so need to deactivate it at the top of the hour (i.e., when seconds are equal to zero).
  // As an additional safety to prevent the output from staying activated for too long, the software deactivates the
  // output whenever seconds is equal to zero (not just at the top of the hour).  That way, the longest the output
  // could ever stay activated is one minute.  As a side effect of this, the output will get deactivated when seconds
  // is equal to zero if the user is manually activating the output, but that should not cause any large issues, since
  // the manual activation by the user is just a convenience feature for testing the output.
  if (seconds == 0)
  {
    if (digitalRead(CLOCK_SYNC) == HIGH)
    {
      digitalWrite(CLOCK_SYNC, LOW);    // De-activate the clock synchronizer circuit
      digitalWrite(RED_LED, RED_LED_INACTIVE);
      Serial.print("PULSE OFF   ");
      Serial.print("Min: ");
      Serial.print(minutes);
      Serial.print("  Sec: ");
      Serial.println(seconds);
    }
  }
  
    // Update the LCD display about every 200 milliseconds
  if (gMainLoopCounter % 2 == 0) {
    updateDisplay();
  }

  // Set main loop timing (approximate is fine)
  delay(100);             // Delay about 100 milliseconds
  gMainLoopCounter++;
}


// Get data from GPS module
void readGPS()
{
  bool done = false;
  int  counter = 0;
  while (!done && (counter < 1000)) {
    counter++;
    // Read data from the GPS
    char c = GPS.read();
    if (c == 0) {
      done = true;
    } else {
      Serial.print(c);
    }
    // Check for new NMEA data received from the GPS module
    if (GPS.newNMEAreceived()) {
      if (GPS.parse(GPS.lastNMEA())) {
        // Increment the number of GPS messages received
        // It seems like the GPS time does not stabilize right away, so compensate by not
        // syncing the RTC to the GPS time until a few GPS messages have been received
        gNumGPSMsgsRcvd++;
        Serial.print("GPS Msgs: ");
        Serial.println(gNumGPSMsgsRcvd);
      } else {
        Serial.println("No GPS parse");
      }
    }
  }
}


// Sync the RTC to the GPS time base to keep the RTC accurate
void syncRTCtoGPS()
{
  // Note: Need to add the "time since last valid GPS time" value (in seconds) to the stored GPS time to get the actual current time
  // to be stored in the RTC time

  Serial.println("*** SYNCING RTC TO GPS TIME ***");

  // Get the current GPS time values and put them in a tm struct
  struct tm gps_tm;
  gps_tm.tm_sec = GPS.seconds;
//  Serial.print("Sec: ");
  Serial.println(gps_tm.tm_sec);
  gps_tm.tm_min = GPS.minute;
//  Serial.print("Min: ");
  Serial.println(gps_tm.tm_min);
  gps_tm.tm_hour = GPS.hour;
//  Serial.print("Hr : ");
  Serial.println(gps_tm.tm_hour);
  gps_tm.tm_mday = GPS.day;
//  Serial.print("Day: ");
  Serial.println(gps_tm.tm_mday);
  gps_tm.tm_mon = GPS.month - 1;
//  Serial.print("Mon: ");
  Serial.println(gps_tm.tm_mon);
  gps_tm.tm_year = GPS.year + 100;
//  Serial.print("Yr : ");
  Serial.println(gps_tm.tm_year);

  // Convert to a time_t value
  time_t t = mktime(&gps_tm);
  Serial.print("mktime: ");
  Serial.println(asctime(&gps_tm));
  Serial.print("t: ");
  Serial.println(t);
  Serial.print("GPSsecSinceTime: ");
  nmea_float_t sst = GPS.secondsSinceTime();
  Serial.println(sst);

  // Add in the "time since last valid GPS time" value (in seconds)
  t += (int)sst;
  Serial.print("t(updated): ");
  Serial.println(t);

  // Save to RTC
  rtc.setTime(t);

  // Output to serial
  Serial.println(ctime(&t));
}


// Update the LCD display
/* LCD display:
*   Line 1:  "UTC: 13:27:42"            (Current UTC time, with "*" added at the end if time is not valid)
*   Line 2:  "Mon Mar 4 13:27:42 2024"  (Current UTC date and time)
*   Line 3:  "GPS Age: 12  Sats: 12"    (GPS Age (seconds since last valid GPS time was received) and number of GPS satellites being used)
*   Line 4:  "Lat: 42.45  Long: -88.42" (Latitude and longitude)
*   Line 5:  "Sync Out: ENABLED"        (Clock sync pulse output state, possible values: "ENABALED", "DISABLED", "HIGH")
*   Line 6:  "Battery: 4.1 V / 95%"     (Internal Lithium-ion battery voltage and state of charge)
*/
void updateDisplay()
{
  gCanvas.fillScreen(ST77XX_BLACK);
  gCanvas.setCursor(0, 17);

  // Line 1
  gCanvas.setTextColor(ST77XX_RED);
  gCanvas.print("UTC: ");
  int hour = rtc.getHour(true);         // true indicates 24 hour time
  if (hour < 10) { gCanvas.print('0'); }
  gCanvas.print(hour);
  gCanvas.print(":");
  int minute = rtc.getMinute();
  if (minute < 10) { gCanvas.print('0'); }
  gCanvas.print(minute);
  gCanvas.print(":");
  int second = rtc.getSecond();
  if (gRTCTimeValid) {
    if (second < 10) { gCanvas.print('0'); }
    gCanvas.println(second);
  } else {
    if (second < 10) { gCanvas.print('0'); }
    gCanvas.print(second);
    gCanvas.println(" *");
  }

  // Line 2
  time_t t = rtc.getEpoch();
  gCanvas.print(ctime(&t));

  // Line 3
  gCanvas.setTextColor(ST77XX_GREEN);
  gCanvas.print("GPS Age: ");
  if (gSecondsSinceLastValidGPSTime < 0.001) {
    // Value is zero, which means no valid GPS time has been received
    gCanvas.print("N/A sec");
  } else if (gSecondsSinceLastValidGPSTime > 9999.0) {
    gCanvas.print("9999+ sec");
  } else {
    gCanvas.print((int)gSecondsSinceLastValidGPSTime);
    gCanvas.print(" sec");
  }
  gCanvas.print("   Sats: ");
  gCanvas.println(GPS.satellites);

  // Line 4
  gCanvas.print("Lat: ");
  gCanvas.print(GPS.latitudeDegrees);
  gCanvas.print("   Long: " );
  gCanvas.println(GPS.longitudeDegrees);

  // Line 5
  gCanvas.setTextColor(ST77XX_BLUE); 
  gCanvas.print("Sync Out: ");
  gCanvas.setTextColor(ST77XX_WHITE);
  if (digitalRead(CLOCK_SYNC) == HIGH) {
    gCanvas.println("HIGH");
  } else if ( (gRTCTimeValid) && (!gSynchronizerOutputManuallyDisabled) ) {
    gCanvas.println("ENABLED");
  } else {
    gCanvas.println("DISABLED");
  }

  // Line 6
  gCanvas.setTextColor(ST77XX_MAGENTA);
  gCanvas.print("Battery: ");
  gCanvas.setTextColor(ST77XX_WHITE);
  if (gMAX17048_OK) {
    gCanvas.print(gLiPo.cellVoltage(), 1);
    gCanvas.print(" V  /  ");
    float cp = gLiPo.cellPercent();
    if (cp > 100.0) cp = 100.0;       // Limit max battery percentage to 100%
    gCanvas.print(cp, 0);
    gCanvas.println("%");
  }

  gDisplay.drawRGBBitmap(0, 0, gCanvas.getBuffer(), 240, 135);
}
